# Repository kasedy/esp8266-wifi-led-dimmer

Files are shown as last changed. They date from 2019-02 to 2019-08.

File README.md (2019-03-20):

# WiFi controlled LED switch / dimmer

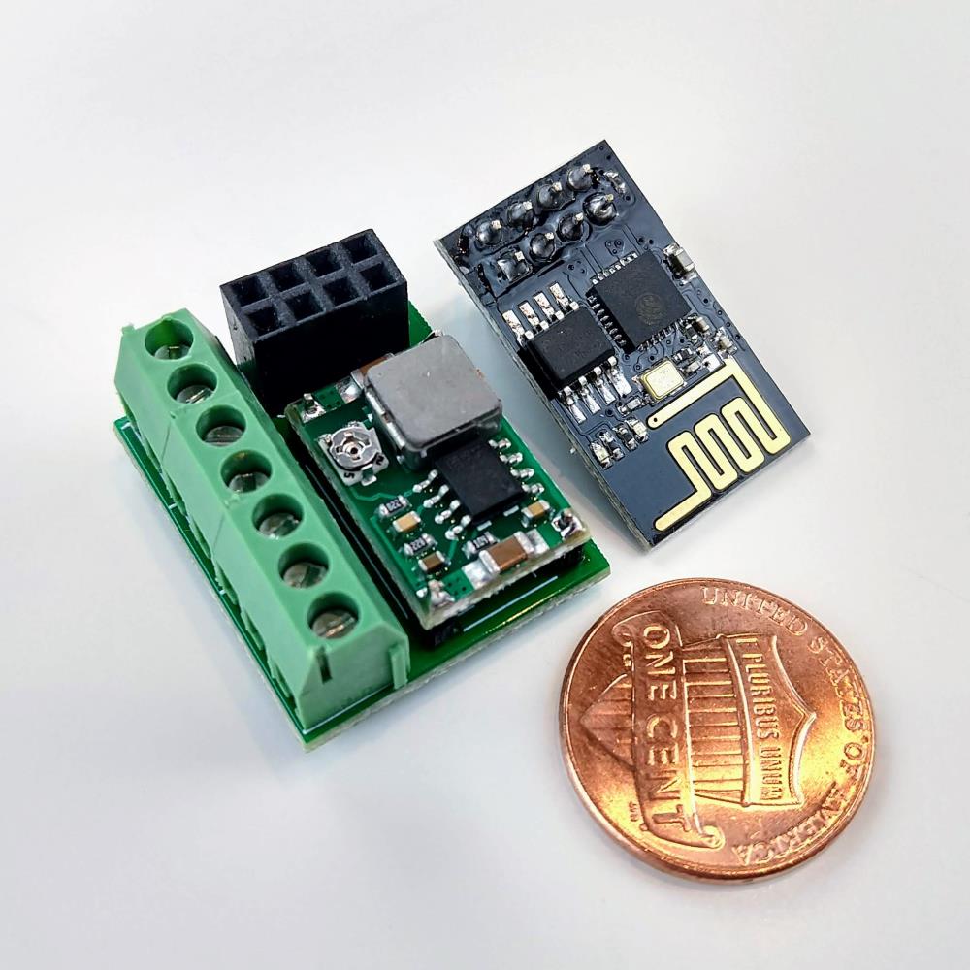
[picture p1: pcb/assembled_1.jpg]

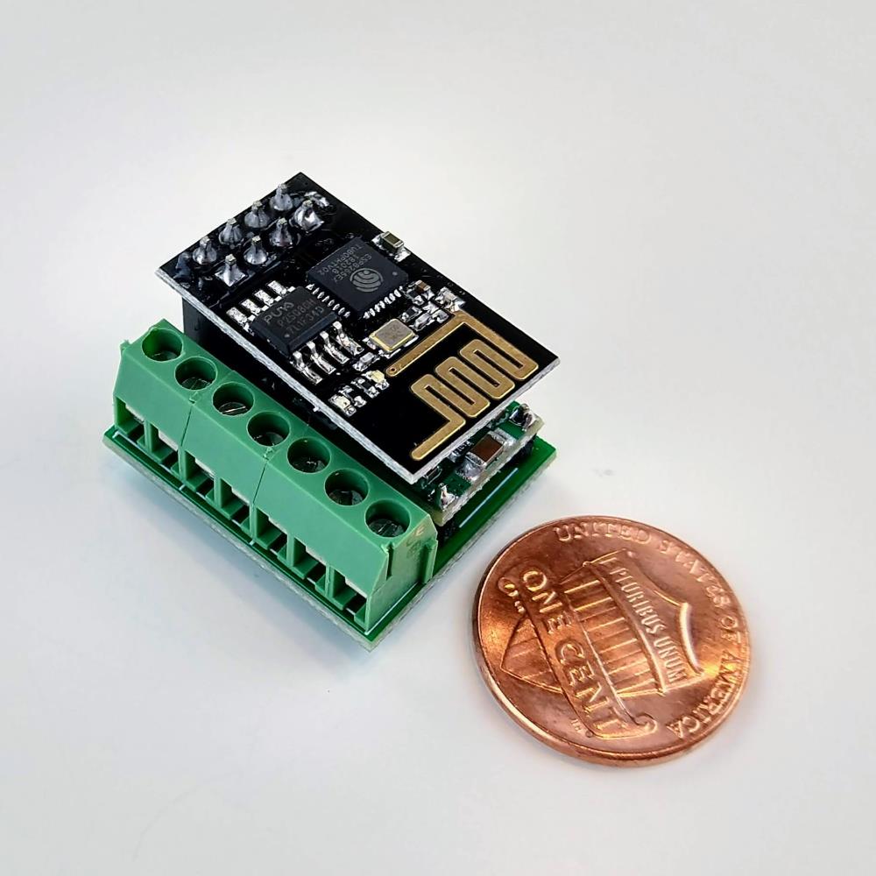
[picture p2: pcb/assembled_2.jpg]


The controller is designed to have extra small size (22x26x14mm), and costs under $2 per item. Four independent channels allow to create lamps with different blink effects or control RGB led strip.
<div style="clear: both;">

Based on ESP8266-01 microcontroller<br/>
Repository store firmware for WiFi controlled LED lamp<br/>
Works with homeassistant<br/>
Supports effects<br/>
Allows to dim light<br/>
Dimming based on PWM<br/>
May work as a WiFi switch<br/>

# Assembling instructions

<a href="http://www.youtube.com/watch?feature=player_embedded&v=8LverFZVN8w" target="_blank">
  Assembling LED dimming switch controller
</a>

# Eagle project for pcb manufactering

| Design | Description |
| :---: | --- |
| *Light&#160;SOT32* | Uses SOT32 MOSFET's mounted under voltage regultar. |
| *Light&#160;SOT32&#160;bottom* | Uses SOT32 MOSFET's mounted on the other side of the board. |
| *Light&#160;TO-220* | Uses TO220 MOSFET's for long led strips that requere high power. |
| *Panelized* | Contains all 3 kind of boards replicated 4 times. Archive contains all necessary files for a manufacterer. Board size does not exceed 100X100mm. It is the smalles and cheappes size. Could be ordered from [jlcpcb.com](https://jlcpcb.com/) for $2. |

`Light SOT32` and `Light SOT32 bottom` are low power versions of the board. It can handle up to 2A per chanel. When `Light TO-220` is a high power board with up to 15A per channel.

# Parts required for one module

| Part | Amount |
| --- | :---: |
| Microcontroller Esp8266-01 | 1 |
| MOSFET ao3400 (for low power board version) | 4 |
| MOSFET P55NF06L (for high power board version) | 4 |
| Buck converter Mini 360 | 1 |
| SMD resistor 0805 10kOh | 2 |
| Pin Header 2x4 2.54mm | 1 |
| Terminal KF350-2P and KF350-3P | 2 |
| Terminal KF350-3P | 1 | 
| Male single row pin 2.54mm | 4 |

# Panelized PCB

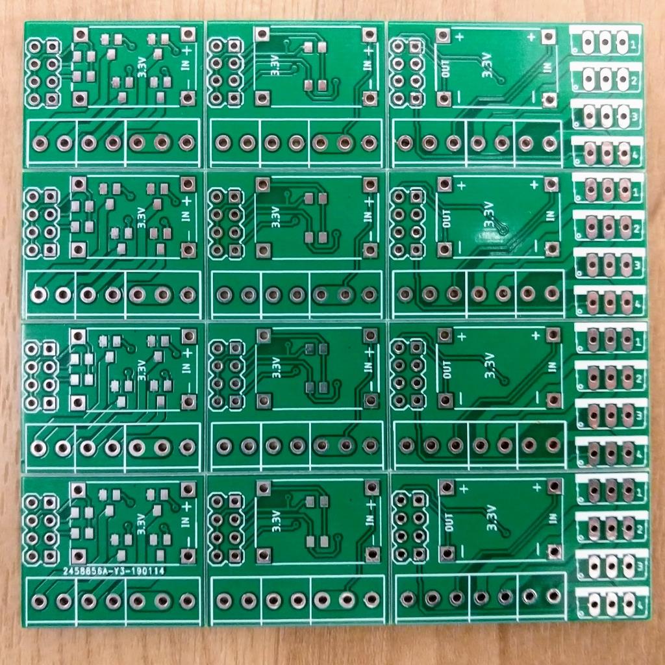
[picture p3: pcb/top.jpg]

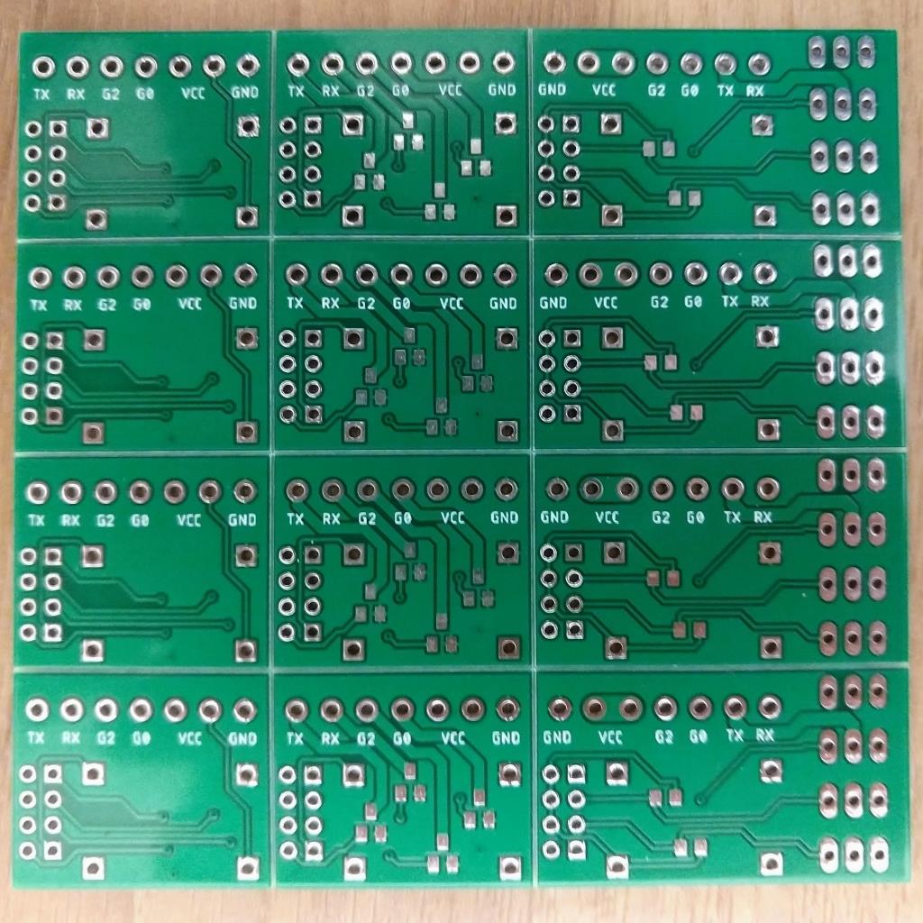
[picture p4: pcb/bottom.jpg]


# Wiring schema

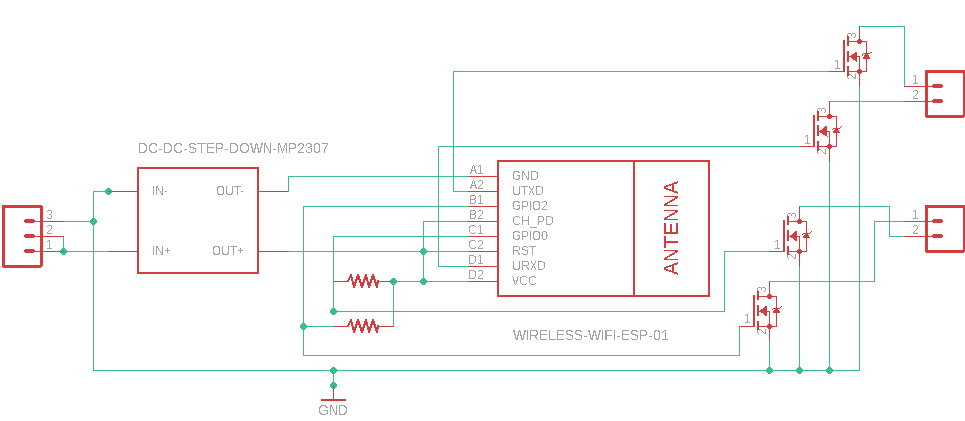
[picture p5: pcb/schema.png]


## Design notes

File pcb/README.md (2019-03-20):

# PCB




The controller is designed to have extra small size (22x26x14mm), and costs under $2 per item. Four independent channels allow to create lamps with different blink effects or control RGB led strip.
<div style="clear: both;"><br/><br/><br/></div>

# Assembling instructions

<a href="http://www.youtube.com/watch?feature=player_embedded&v=8LverFZVN8w" target="_blank">
  Assembling LED dimming switch controller
</a>

# Eagle project for pcb manufactering

| Design | Description |
| :---: | --- |
| *Light&#160;SOT32* | Uses SOT32 MOSFET's mounted under voltage regultar. |
| *Light&#160;SOT32&#160;bottom* | Uses SOT32 MOSFET's mounted on the other side of the board. |
| *Light&#160;TO-220* | Uses TO220 MOSFET's for long led strips that requere high power. |
| *Panelized* | Contains all 3 kind of boards replicated 4 times. Archive contains all necessary files for a manufacterer. Board size does not exceed 100X100mm. It is the smalles and cheappes size. Could be ordered from [jlcpcb.com](https://jlcpcb.com/) for $2. |

`Light SOT32` and `Light SOT32 bottom` are low power versions of the board. It can handle up to 2A per chanel. When `Light TO-220` is a high power board with up to 15A per channel.

# Parts required for one module

| Part | Amount |
| --- | :---: |
| Microcontroller Esp8266-01 | 1 |
| MOSFET ao3400 (for low power board version) | 4 |
| MOSFET P55NF06L (for high power board version) | 4 |
| Buck converter Mini 360 | 1 |
| SMD resistor 0805 10kOh | 2 |
| Pin Header 2x4 2.54mm | 1 |
| Terminal KF350-2P and KF350-3P | 2 |
| Terminal KF350-3P | 1 | 
| Male single row pin 2.54mm | 4 |

# Panelized PCB




# Wiring schema



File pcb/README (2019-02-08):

# Eagle project for manufactering pcb

`Light SOT32` pcb uses SOT32 MOSFET's mounted under voltage regultaro
`Light SOT32 bottom` pcb uses SOT32 MOSFET's mounted on the other side of the board
`Light TO-220` pcb uses TO220 MOSFET's for long led strips that requere more power
`Panelized` contains all 3 kind of boards multiplied 4 times. Archive contains all necessary files for manufacterer. Board size does not exceed 100X100mm. It is the smalles and cheappes size.

# Recomended part list (www.aliexpress.com)

ESP8266: ESP-01
SOT32 MOSFET: ao3400
TO220 MOSFET: P55NF06L
Voltage regulator: Mini 360
Resistors 0805: 10kOh
Pin Header 2x4 Pin 2.54mm 
Terminals: KF350-2P and KF350-3P

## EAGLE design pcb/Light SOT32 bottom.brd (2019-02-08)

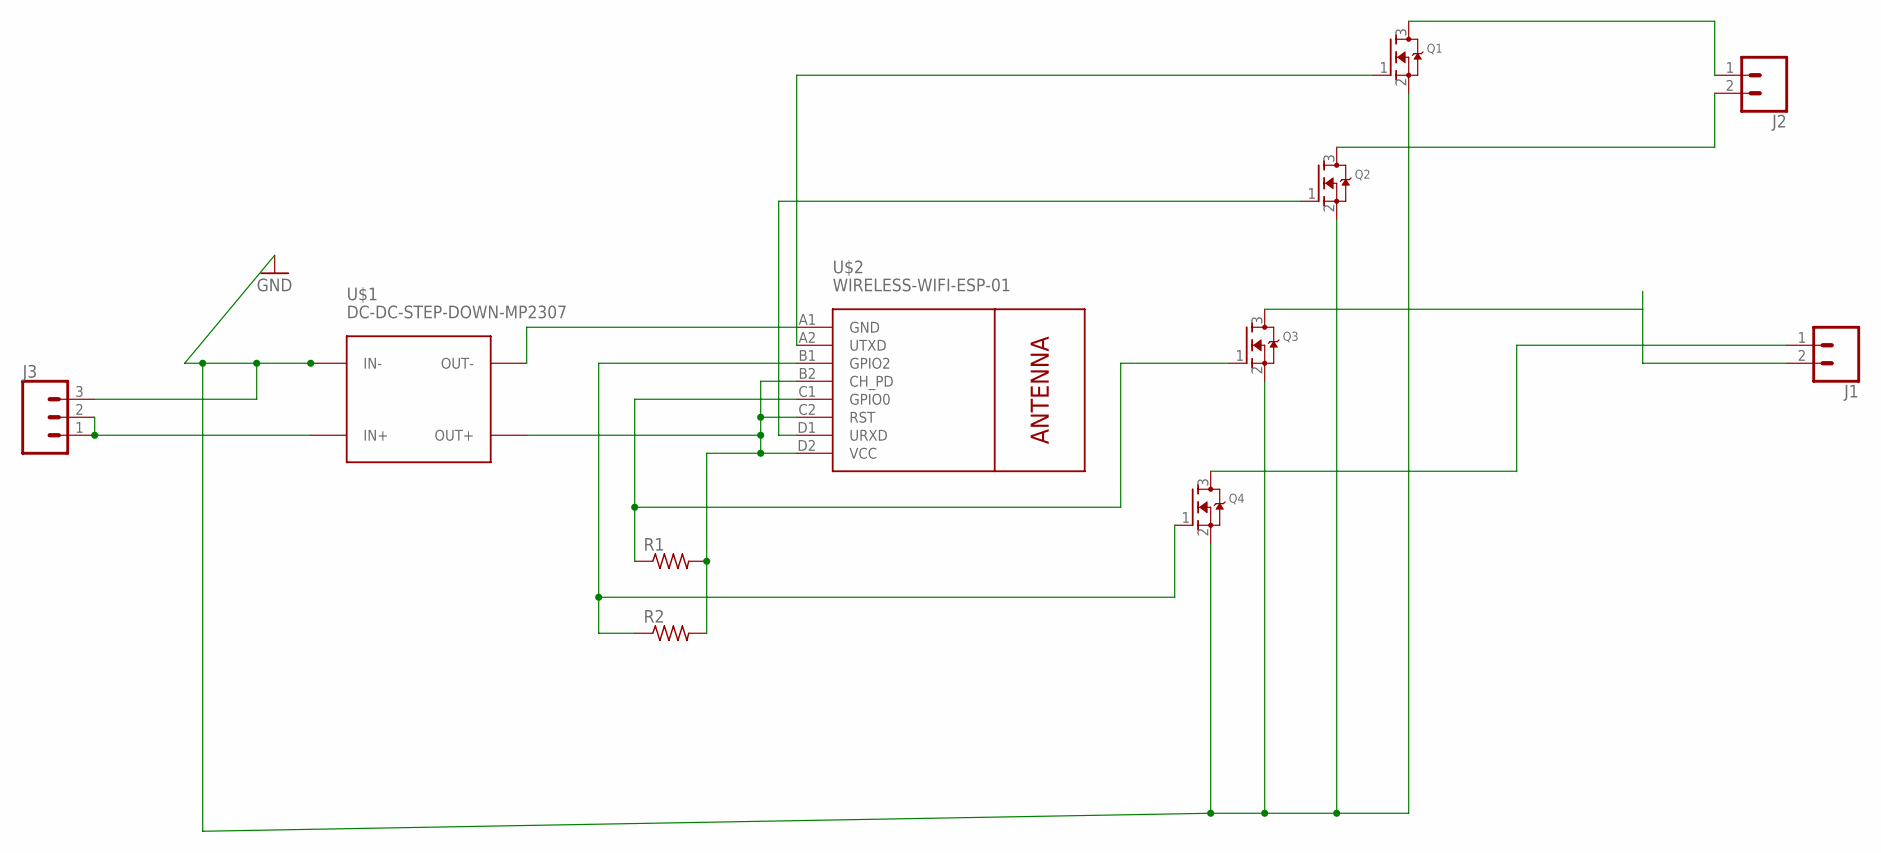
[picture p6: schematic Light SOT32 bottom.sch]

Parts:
J1, J2: CONN_023.5MM; SCREWTERMINAL-3.5MM-2
J3: CONN_03SCREW; SCREWTERMINAL-3.5MM-3
Q1, Q2, Q3, Q4: MOSFET-NREFLOW; SOT23
R1, R2: R-US_R0805; R0805
U$1: DC-DC-STEP-DOWN-MP2307
U$2: WIRELESS-WIFI-ESP-01

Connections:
GND: J3.3, Q1.2 (S), Q2.2 (S), Q3.2 (S), Q4.2 (S), U$1.IN-
unnamed: R1.2, R2.2, U$1.OUT+, U$2.B2 (CH_PD), U$2.C2 (RST), U$2.D2 (VCC)
unnamed: Q2.1 (G), U$2.D1 (URXD)
unnamed: U$1.OUT-, U$2.A1 (GND)
unnamed: Q3.1 (G), R1.1, U$2.C1 (GPIO0)
unnamed: Q4.1 (G), R2.1, U$2.B1 (GPIO2)
unnamed: Q1.1 (G), U$2.A2 (UTXD)
unnamed: J3.1, J3.2, U$1.IN+
unnamed: J2.2, Q2.3 (D)
unnamed: J2.1, Q1.3 (D)
unnamed: J1.1, Q4.3 (D)
unnamed: J1.2, Q3.3 (D)

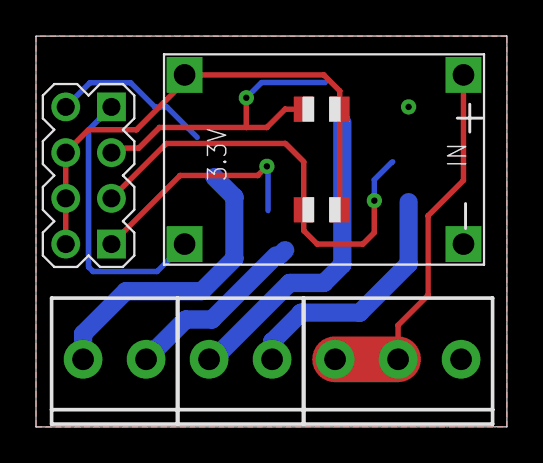
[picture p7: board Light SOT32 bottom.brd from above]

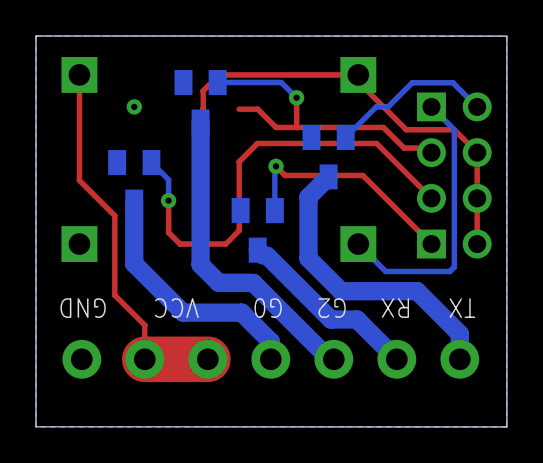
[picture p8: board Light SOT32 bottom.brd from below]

Board: 2 copper layers, 26.2 x 21.7 mm, 11 parts (4 on the bottom side), 12 nets.

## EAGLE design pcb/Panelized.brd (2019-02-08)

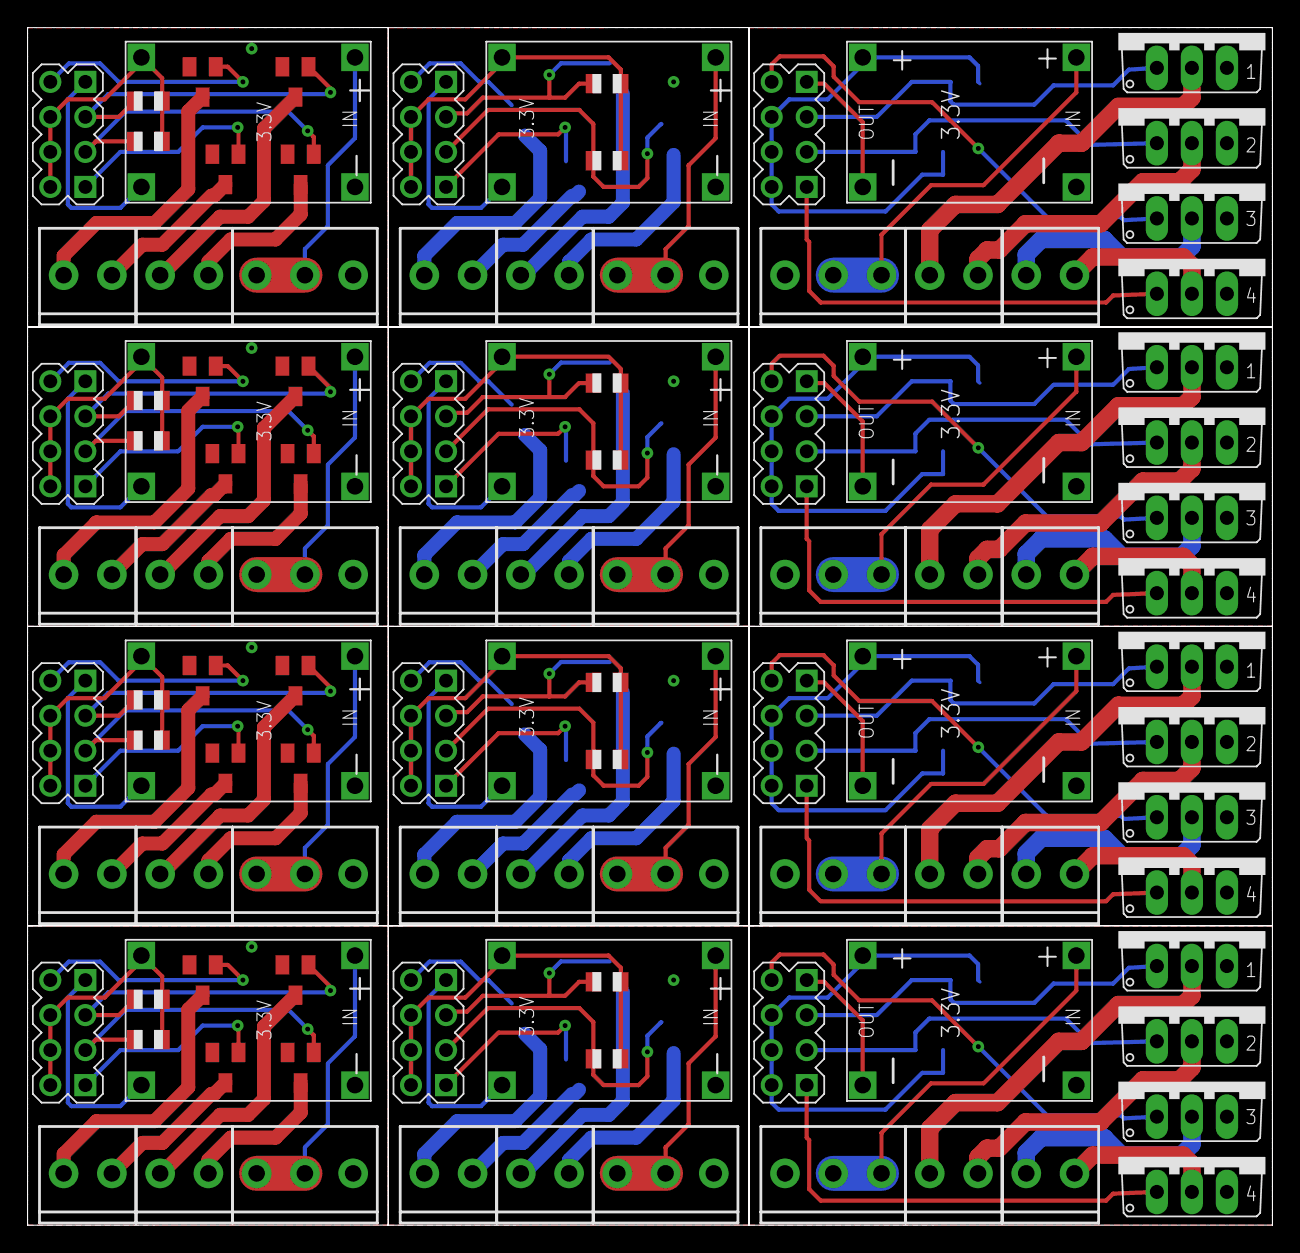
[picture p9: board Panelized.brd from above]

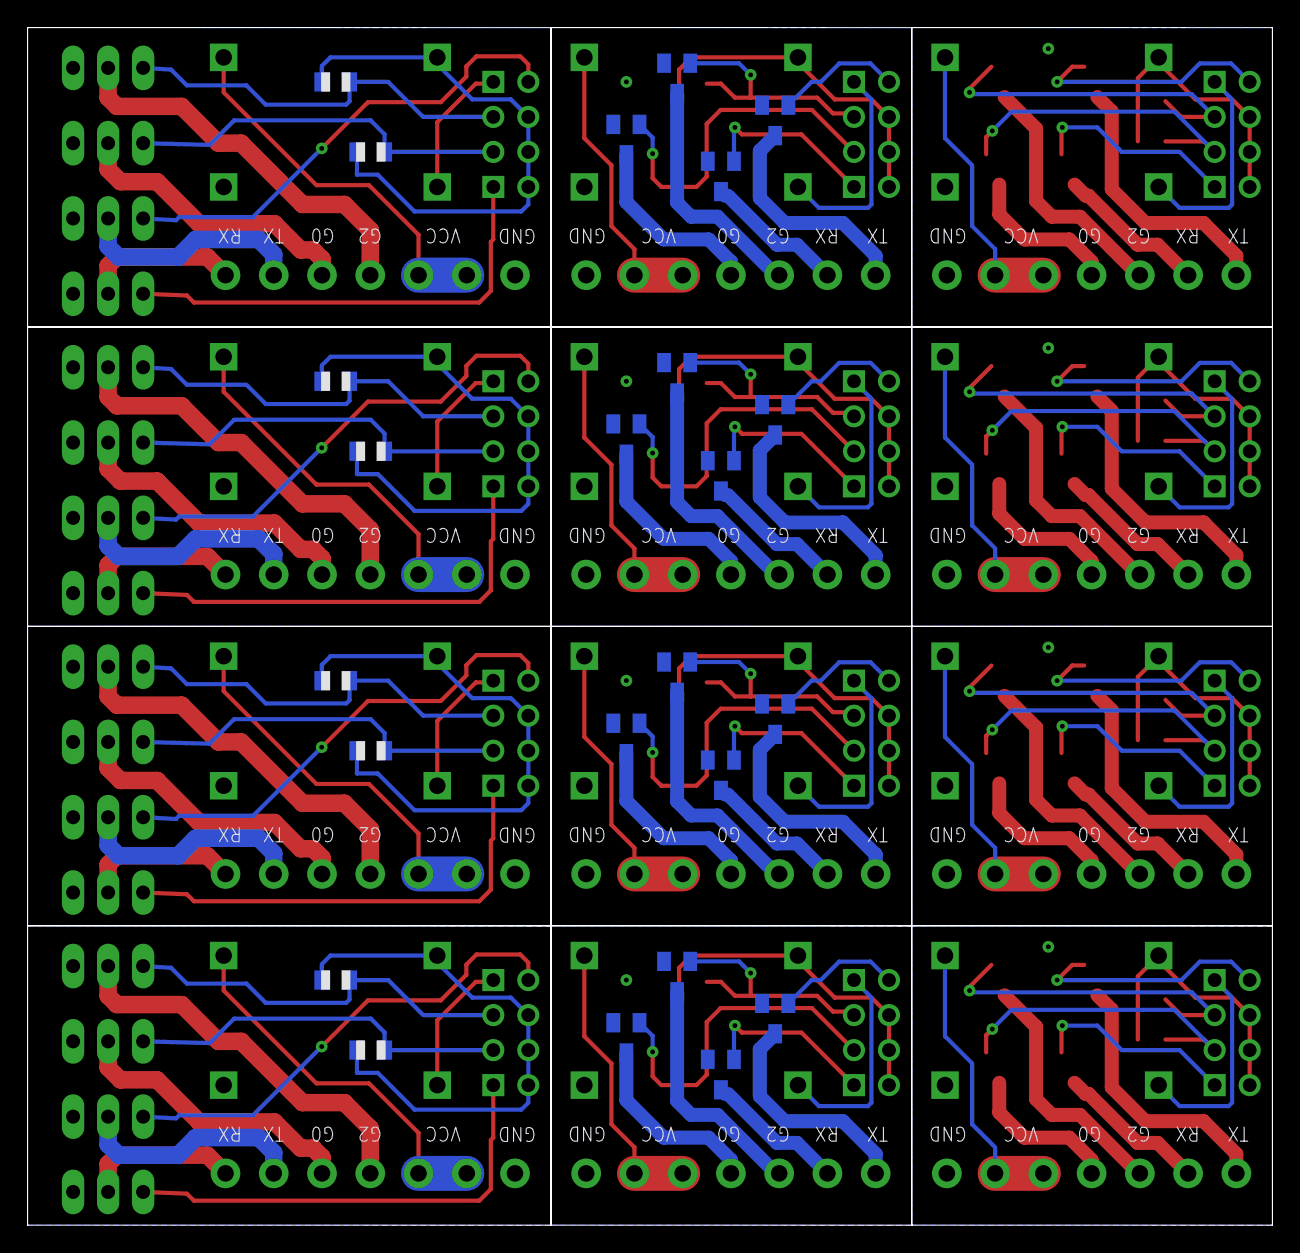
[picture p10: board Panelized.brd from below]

Board: 2 copper layers, 90.3 x 86.9 mm, 132 parts (24 on the bottom side), 144 nets.

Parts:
J1, J2, J4, J5, J7, J8, J10, J11, J13, J14, J16, J17, J19, J20, J22, J23, J25, J26, J28, J29, J31, J32, J34, J35: SCREWTERMINAL-3.5MM-2
J3, J6, J9, J12, J15, J18, J21, J24, J27, J30, J33, J36: SCREWTERMINAL-3.5MM-3
Q1, Q2, Q3, Q4, Q5, Q6, Q7, Q8, Q13, Q14, Q15, Q16, Q17, Q18, Q19, Q20, Q25, Q26, Q27, Q28, Q29, Q30, Q31, Q32, Q37, Q38, Q39, Q40, Q41, Q42, Q43, Q44: SOT23
Q9, Q10, Q11, Q12, Q21, Q22, Q23, Q24, Q33, Q34, Q35, Q36, Q45, Q46, Q47, Q48: TO220V
R1, R2, R3, R4, R5, R6, R7, R8, R9, R10, R11, R12, R13, R14, R15, R16, R17, R18, R19, R20, R21, R22, R23, R24: R0805
U$1, U$3, U$5, U$7, U$9, U$11, U$13, U$15, U$17, U$19, U$21, U$23: DC-DC-STEP-DOWN-MP2307
U$2, U$4, U$6, U$8, U$10, U$12, U$14, U$16, U$18, U$20, U$22, U$24: WIRELESS-WIFI-ESP-01

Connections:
GND: J3.3, Q1.2, Q2.2, Q3.2, Q4.2, U$1.IN-
GND1: J6.3, Q5.2, Q6.2, Q7.2, Q8.2, U$3.IN-
GND2: J9.1, Q9.3, Q10.3, Q11.3, Q12.3, U$5.IN-
GND3: J12.3, Q13.2, Q14.2, Q15.2, Q16.2, U$7.IN-
GND4: J15.3, Q17.2, Q18.2, Q19.2, Q20.2, U$9.IN-
GND5: J18.1, Q21.3, Q22.3, Q23.3, Q24.3, U$11.IN-
GND6: J21.3, Q25.2, Q26.2, Q27.2, Q28.2, U$13.IN-
GND7: J24.3, Q29.2, Q30.2, Q31.2, Q32.2, U$15.IN-
GND8: J27.1, Q33.3, Q34.3, Q35.3, Q36.3, U$17.IN-
GND9: J30.3, Q37.2, Q38.2, Q39.2, Q40.2, U$19.IN-
GND10: J33.3, Q41.2, Q42.2, Q43.2, Q44.2, U$21.IN-
GND11: J36.1, Q45.3, Q46.3, Q47.3, Q48.3, U$23.IN-
unnamed: R1.2, R2.2, U$1.OUT+, U$2.B2, U$2.C2, U$2.D2
unnamed: Q2.1, U$2.D1
unnamed: U$1.OUT-, U$2.A1
unnamed: Q3.1, R1.1, U$2.C1
unnamed: Q4.1, R2.1, U$2.B1
unnamed: Q1.1, U$2.A2
unnamed: J3.1, J3.2, U$1.IN+
unnamed: J2.2, Q2.3
unnamed: J2.1, Q1.3
unnamed: J1.1, Q4.3
unnamed: J1.2, Q3.3
unnamed: R3.2, R4.2, U$3.OUT+, U$4.B2, U$4.C2, U$4.D2
unnamed: U$3.OUT-, U$4.A1
unnamed: Q7.1, R3.1, U$4.C1
unnamed: Q8.1, R4.1, U$4.B1
unnamed: Q6.1, U$4.D1
unnamed: Q5.1, U$4.A2
unnamed: J5.2, Q6.3
unnamed: J5.1, Q5.3
unnamed: J4.1, Q8.3
unnamed: J4.2, Q7.3
unnamed: J6.1, J6.2, U$3.IN+
unnamed: R5.2, R6.2, U$5.OUT+, U$6.B2, U$6.C2, U$6.D2
unnamed: U$5.OUT-, U$6.A1
unnamed: Q11.1, R5.1, U$6.C1
unnamed: Q12.1, R6.1, U$6.B1
unnamed: Q10.1, U$6.D1
unnamed: J7.1, Q12.2
unnamed: J7.2, Q11.2
unnamed: J9.2, J9.3, U$5.IN+
unnamed: Q9.1, U$6.A2
unnamed: J8.1, Q9.2
unnamed: J8.2, Q10.2
unnamed: R7.2, R8.2, U$7.OUT+, U$8.B2, U$8.C2, U$8.D2
unnamed: U$7.OUT-, U$8.A1
unnamed: Q15.1, R7.1, U$8.C1
unnamed: Q16.1, R8.1, U$8.B1
unnamed: Q14.1, U$8.D1
unnamed: Q13.1, U$8.A2
unnamed: J11.2, Q14.3
unnamed: J11.1, Q13.3
unnamed: J10.1, Q16.3
unnamed: J10.2, Q15.3
unnamed: J12.1, J12.2, U$7.IN+
unnamed: R9.2, R10.2, U$9.OUT+, U$10.B2, U$10.C2, U$10.D2
unnamed: U$9.OUT-, U$10.A1
unnamed: Q19.1, R9.1, U$10.C1
unnamed: Q20.1, R10.1, U$10.B1
unnamed: Q18.1, U$10.D1
unnamed: Q17.1, U$10.A2
unnamed: J14.2, Q18.3
unnamed: J14.1, Q17.3
unnamed: J13.1, Q20.3
unnamed: J13.2, Q19.3
unnamed: J15.1, J15.2, U$9.IN+
unnamed: R11.2, R12.2, U$11.OUT+, U$12.B2, U$12.C2, U$12.D2
unnamed: U$11.OUT-, U$12.A1
unnamed: Q23.1, R11.1, U$12.C1
unnamed: Q24.1, R12.1, U$12.B1
unnamed: Q22.1, U$12.D1
unnamed: J16.1, Q24.2
unnamed: J16.2, Q23.2
unnamed: J18.2, J18.3, U$11.IN+
unnamed: Q21.1, U$12.A2
unnamed: J17.1, Q21.2
unnamed: J17.2, Q22.2
unnamed: R13.2, R14.2, U$13.OUT+, U$14.B2, U$14.C2, U$14.D2
unnamed: U$13.OUT-, U$14.A1
unnamed: Q27.1, R13.1, U$14.C1
unnamed: Q28.1, R14.1, U$14.B1
unnamed: Q26.1, U$14.D1
unnamed: Q25.1, U$14.A2
unnamed: J20.2, Q26.3
unnamed: J20.1, Q25.3
unnamed: J19.1, Q28.3
unnamed: J19.2, Q27.3
unnamed: J21.1, J21.2, U$13.IN+
unnamed: R15.2, R16.2, U$15.OUT+, U$16.B2, U$16.C2, U$16.D2
unnamed: U$15.OUT-, U$16.A1
unnamed: Q31.1, R15.1, U$16.C1
unnamed: Q32.1, R16.1, U$16.B1
unnamed: Q30.1, U$16.D1
unnamed: Q29.1, U$16.A2
unnamed: J23.2, Q30.3
unnamed: J23.1, Q29.3
unnamed: J22.1, Q32.3
unnamed: J22.2, Q31.3
unnamed: J24.1, J24.2, U$15.IN+
unnamed: R17.2, R18.2, U$17.OUT+, U$18.B2, U$18.C2, U$18.D2
unnamed: U$17.OUT-, U$18.A1
unnamed: Q35.1, R17.1, U$18.C1
unnamed: Q36.1, R18.1, U$18.B1
unnamed: Q34.1, U$18.D1
unnamed: J25.1, Q36.2
unnamed: J25.2, Q35.2
unnamed: J27.2, J27.3, U$17.IN+
unnamed: Q33.1, U$18.A2
unnamed: J26.1, Q33.2
unnamed: J26.2, Q34.2
unnamed: R19.2, R20.2, U$19.OUT+, U$20.B2, U$20.C2, U$20.D2
unnamed: U$19.OUT-, U$20.A1
unnamed: Q39.1, R19.1, U$20.C1
unnamed: Q40.1, R20.1, U$20.B1
unnamed: Q38.1, U$20.D1
unnamed: Q37.1, U$20.A2
unnamed: J29.2, Q38.3
unnamed: J29.1, Q37.3
unnamed: J28.1, Q40.3
unnamed: J28.2, Q39.3
unnamed: J30.1, J30.2, U$19.IN+
unnamed: R21.2, R22.2, U$21.OUT+, U$22.B2, U$22.C2, U$22.D2
unnamed: U$21.OUT-, U$22.A1
unnamed: Q43.1, R21.1, U$22.C1
unnamed: Q44.1, R22.1, U$22.B1
unnamed: Q42.1, U$22.D1
unnamed: Q41.1, U$22.A2
unnamed: J32.2, Q42.3
unnamed: J32.1, Q41.3
unnamed: J31.1, Q44.3
unnamed: J31.2, Q43.3
unnamed: J33.1, J33.2, U$21.IN+
unnamed: R23.2, R24.2, U$23.OUT+, U$24.B2, U$24.C2, U$24.D2
unnamed: U$23.OUT-, U$24.A1
unnamed: Q47.1, R23.1, U$24.C1
unnamed: Q48.1, R24.1, U$24.B1
unnamed: Q46.1, U$24.D1
unnamed: J34.1, Q48.2
unnamed: J34.2, Q47.2
unnamed: J36.2, J36.3, U$23.IN+
unnamed: Q45.1, U$24.A2
unnamed: J35.1, Q45.2
unnamed: J35.2, Q46.2

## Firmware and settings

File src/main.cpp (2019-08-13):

#include "LightController.h"
#include "helpers.h"
#include "effects.h"
#include "LedDriver.h"
#include "MqttProcessor.h"
#include "ota.h"
#include "VoiceControl.h"

#include <WiFiManager.h>
#include <Hash.h>

LightController *lightController;

void setupWifi() {
  LedDriver blueLed(LEAD_INDICATOR_PIN, HIGH);
  blueLed.blink(500);
  WiFiManager wifiManager;
  wifiManager.autoConnect(HOSTNAME);
  blueLed.setHigh();
}

void setup() { 
#if LOGGING
  Serial.begin(74880, SERIAL_8N1, SERIAL_TX_ONLY);
  Serial.setDebugOutput(true);
#endif 
  lightController = new LightController(LED_PINS, defaultEffects());
  VoiceControl::setup();
  setupWifi();
  Ota::setup();
  randomSeed(ESP.getCycleCount());
  MqttProcessor::setup();
}

void loop() {
  // Stage 0: all what is not related to Light
  Ota::loop();
  // Stage 1: read all possible sources that could change Ligst state

  // Stage 2: notify all sources about Light changes
  if (lightController->isChanged()) {
    MqttProcessor::broadcastStateViaMqtt();
  }
  // Stage 3: play light animation and clear change flags
  lightController->loop();
}

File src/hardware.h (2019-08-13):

#pragma once

#if defined(HARDWARE_COINTREAU_BOTTLE)
  #define DEVICE_TYPE "cointreau_bottle"
  #define DEVICE_NAME "Cointreau Bottle"
  #define LED_PINS {0, 1, 2, 3}
#elif defined(HARDWARE_COINTREAU_BOTTLE_2)
  #define DEVICE_TYPE "cointreau_bottle_2"
  #define DEVICE_NAME "Cointreau Bottle 2"
  #define LED_PINS {3, 12, 13, 16}
  #define CAPACITIVE_SENSOR_SEND_PIN 5
  #define CAPACITIVE_SENSOR_RECEIVE_PIN 4
#elif defined(HARDWARE_TEST)
  #define DEVICE_TYPE "DevEnv"
  #define DEVICE_NAME "Testing and Development"
  #define LED_PINS {3, 12, 13, 14, 16}
  #define LOGGING true
 #define CAPACITIVE_SENSOR_SEND_PIN 5
 #define CAPACITIVE_SENSOR_RECEIVE_PIN 4
#elif defined(HARDWARE_KITCHEN_LIGHT)
  #define DEVICE_TYPE "kitchen_light"
  #define DEVICE_NAME "Kitchen Light"
  #define LED_PINS {{0, 2}}
  #define NO_WEB_PORTAL
#elif defined(HARDWARE_HANGING_BULBS)
  #define DEVICE_TYPE "hanging_bulbs"
  #define DEVICE_NAME "Hanging bulbs"
  #define LED_PINS {0}  
#endif

#define LEAD_INDICATOR_PIN 2

#define MQTT_SERVER "raspberrypi.local"
#define MQTT_PORT 1883

#define CONFIG_MQTT_PAYLOAD_ON "ON"
#define CONFIG_MQTT_PAYLOAD_OFF "OFF"

#ifdef BOARD_ID
  #define HOSTNAME DEVICE_TYPE "_" STRINGIZE(BOARD_ID)
  #define LED_CONFIG_MQTT_TOPIC_COMMAND "homeassistant/light/" STRINGIZE(BOARD_ID) "/" DEVICE_TYPE
  #define DEVICE_FULL_NAME DEVICE_NAME " " STRINGIZE(BOARD_ID)
#else
  #define HOSTNAME DEVICE_TYPE
  #define LED_CONFIG_MQTT_TOPIC_COMMAND "homeassistant/light/" DEVICE_TYPE
  #define DEVICE_FULL_NAME DEVICE_NAME
#endif

#define LED_CONFIG_MQTT_TOPIC_CONFIG LED_CONFIG_MQTT_TOPIC_COMMAND "/config"
#define LED_CONFIG_MQTT_TOPIC_STATE LED_CONFIG_MQTT_TOPIC_COMMAND "/state"

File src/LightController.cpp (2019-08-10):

#include "LightController.h"

#include "helpers.h"

#include "animations/all.h"

LightController::LightController(const std::vector<PinStatus> &pinsGpio, const std::vector<Effect> &effects) :
    brightness(255),
    animationSpeed(255 / 2),
    pins(pinsGpio), 
    effects(filter_vector(effects, [&](Effect e){ return pinsGpio.size() >= e.pinsRequires; })),
    currentEffect(nullptr),
    currentAnimationIndex(-1),
    stateOn(false),
    brightnessChanged(false),
    stateOnChanged(false),
    effectChanged(false) {
  for (int i = 0; i < getLedCount(); ++i) {
    for (int gpio : pins[i].gpio) {
      DBG("Set pin %d to output\n", gpio);
      pinMode(gpio, OUTPUT);
      setPinValue(i, pins[i].brightness);
    }
  }
  if (effects.empty()) {
    currentEffect = new NoAnimation(this);
  } else {
    setAnimationByIndex(0);
  }
}

LightController::~LightController() {
}

size_t LightController::getAnimationCount() {
  return effects.size();
}

const char* LightController::getAnimationName(size_t index) {
  return effects[index].name;
}

uint8_t LightController::getLedCount() const {
  return pins.size();
}   

void LightController::setPinValue(uint8_t pinIndex, uint8_t brightness) {
  int pwmDuty = map(brightness, 0, 255, 0, 1023);
  for (int gpio : pins[pinIndex].gpio) {
    analogWrite(gpio, pwmDuty);
  }
  pins[pinIndex].brightness = brightness;
}

void LightController::setAllPinValue(uint8_t brightness) {
  for (uint8_t i = 0; i < getLedCount(); ++i) {
    setPinValue(i, brightness);
  }    
}

void LightController::setLightBrightness(uint8_t newMaxBrightness) {
  if (brightness == newMaxBrightness) {
    return;
  }
  brightness = newMaxBrightness;
  brightnessChanged = true;
}

void LightController::setAnimationSpeed(uint8_t newAnimationSpeed) {
  if (animationSpeed == newAnimationSpeed) {
    return;
  }
  animationSpeed = newAnimationSpeed;
  animationSpeedChanged = true;
}

void LightController::setStateOn(bool newStateOn) {
  if (stateOn == newStateOn) {
    return;
  }
  stateOn = newStateOn;
  stateOnChanged = true;
}

  void LightController::toggleState() {
    setStateOn(!isOn());
  }

void LightController::setAnimationByName(const char* effectName) {
  for (size_t animationIndex = 0; animationIndex < effects.size(); ++animationIndex) {
    if (strcmp(effects[animationIndex].name, effectName) == 0) {
      setAnimationByIndex(animationIndex);
      return;
    }
  }
}

void LightController::nextAnimation() {
  uint8_t animationIndex = getCurrentAnimationIndex();
  if (++animationIndex >= effects.size()) {
    animationIndex = 0;
  }
  setAnimationByIndex(animationIndex);
}

void LightController::setAnimationByIndex(uint8_t animationIndex) {
  if (currentAnimationIndex == animationIndex 
      || animationIndex >= effects.size()) {
    return;
  }
  if (currentEffect) {
    delete currentEffect;
  }
  const Effect &effectInfo = effects[animationIndex];
  currentEffect = effectInfo.animationBuilder(this);
  effectChanged = true;
  currentAnimationIndex = animationIndex;
}

void LightController::loop() {
  currentEffect->handle();
  brightnessChanged = false;
  stateOnChanged = false;
  effectChanged = false;
  animationSpeedChanged = false;
}

uint8_t LightController::getLedBrightness(uint8_t pinIndex) const {
  return pins[pinIndex].brightness;
}

uint8_t LightController::getLightBrightness() const {
  return brightness;
}

uint8_t LightController::getCurrentAnimationIndex() {
  return currentAnimationIndex;
}

const char* LightController::getCurrentAnimationName() const {
  return effects[currentAnimationIndex].name;
}

uint8_t LightController::getAnimationSpeed() const {
  return animationSpeed;
}

bool LightController::isOn() const {
  return stateOn;
}

bool LightController::isMaxBrightensChanged() const {
  return brightnessChanged;
}

bool LightController::isStateOnChanged() const {
  return stateOnChanged;
}

bool LightController::isEffectChanged() const {
  return effectChanged;
}

bool LightController::isAnimationSpeedChanged() const {
  return animationSpeedChanged;
}

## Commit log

2019-02-08 added PCB boards
    [Light SOT32 bottom.brd, Light SOT32 bottom.sch, Light SOT32.brd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]
2019-02-08 added photos of pcb
2019-03-20 do no publish last will, home assistant gets crazy if device connect-disconnect several times
2019-05-03 Added simple driver for LEDs that can blink a pattern in cycle.
2019-05-12 Developing a new board with touch sensor
2019-05-12 Added support of touch button
2019-05-13 Blink with blue led if is in configuration mode
2019-05-14 reset device settings on multiple clicks (>=20)
2019-05-15 Improved touch button
2019-08-02 Changed effect number; Fixed linux build; Added remore debug for sensor button;
    [hardware.h, main.cpp]
2019-08-09 improved emergency protocol and replaced wifi manager
    [hardware.h, main.cpp]
2019-08-13 removed CapacitiveSensorButton
